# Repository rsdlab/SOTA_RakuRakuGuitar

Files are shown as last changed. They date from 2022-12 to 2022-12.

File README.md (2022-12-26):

 # 作品について　　

らくラクギターは誰でもかっこよく簡単に弾けるをコンセプトに開発されたギターである。　
　
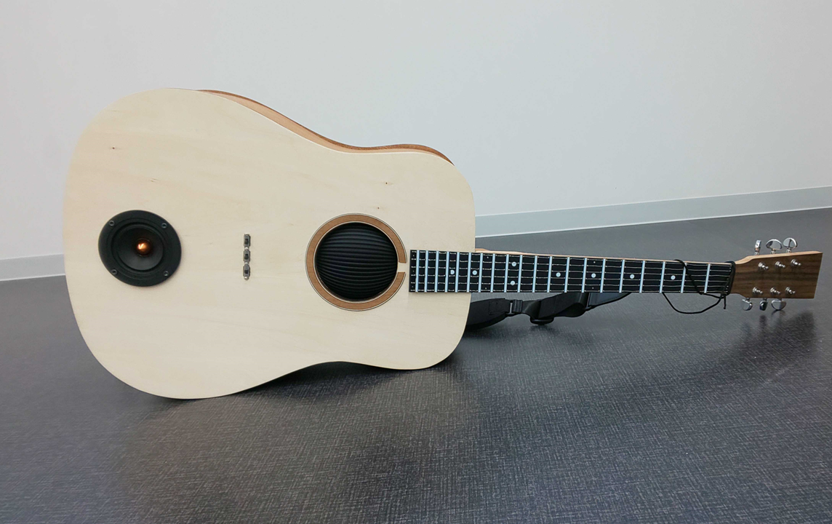
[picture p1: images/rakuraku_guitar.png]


マイコンはSONY製のSPRESENSEを使用している。　　

このらくラクギターには3種類のモードがある。　　

* ビギナーモード　ホイールを回すだけで演奏できるモード　　
* コードモード　弦を模したタッチセンサを1箇所もしくは2箇所押さえるだけで演奏できるモード　　
* マニュアルモード　本物のギターと同様に演奏できるモード　　

らくラクギターはM,m,7,sus4,dim,aug,M7,m7,7sus4に対応している。　　

らくラクギターの製作から実際に動かすまでの手順を以下に示す。　

1.　必要な部品の準備　　

2.　ギターのハード作成　　

3.　回路の作成　　

4.　動かすための準備　　

5.　らくラクギターの動かし方　

以下ではこれらを詳細に述べる。　　

 # 製作&動作手順　　
 ## 必要な部品の準備　　
下記の部品表の通りに各種部品を用意する。

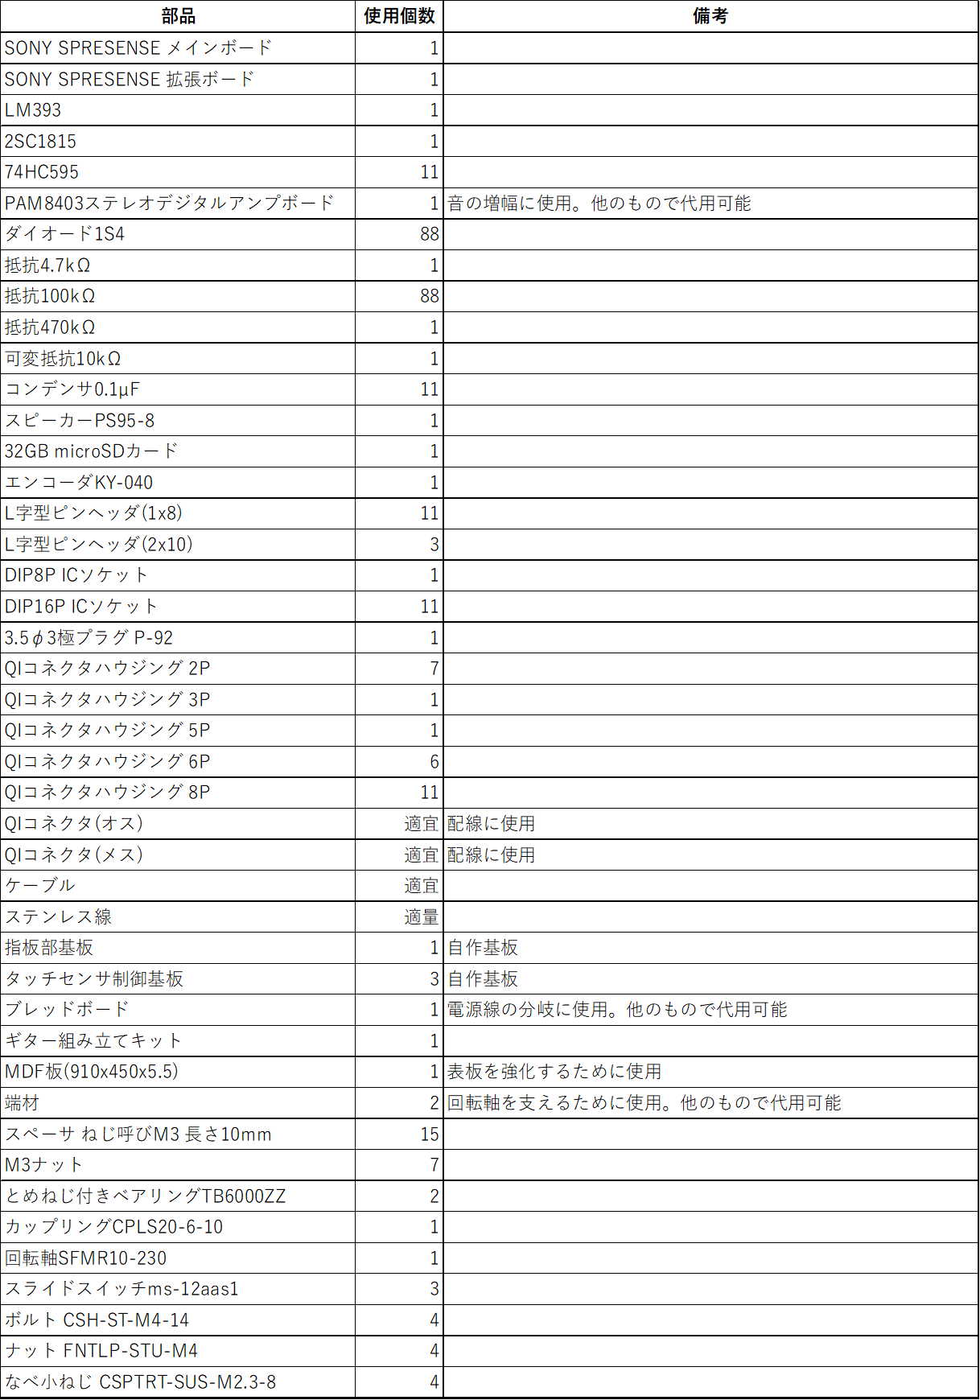
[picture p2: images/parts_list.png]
　　

## ギターのハード作成　　
こちらの動画を参考にギターを組み立てる。[youtubeへ移動](https://www.youtube.com/watch?v=TPaNkqSTSBw)　　
　　

表面の板を部品表にもあるベニヤ板で代替した。　　

タッチセンサやグランド線を通すためのスペースはギターのネックをノミや彫刻刀で彫る。　　

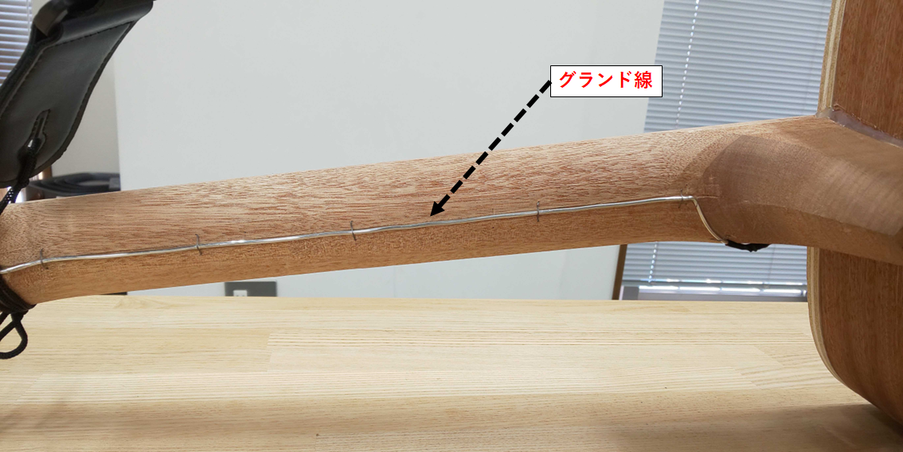
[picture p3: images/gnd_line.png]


また、設計図を基に固定を行う。　　

 ## 回路の作成　　
下記の回路図の通りに部品をはんだづけし、回路を作成する。

※下のタッチセンサ制御基板の配線の図も見てください。

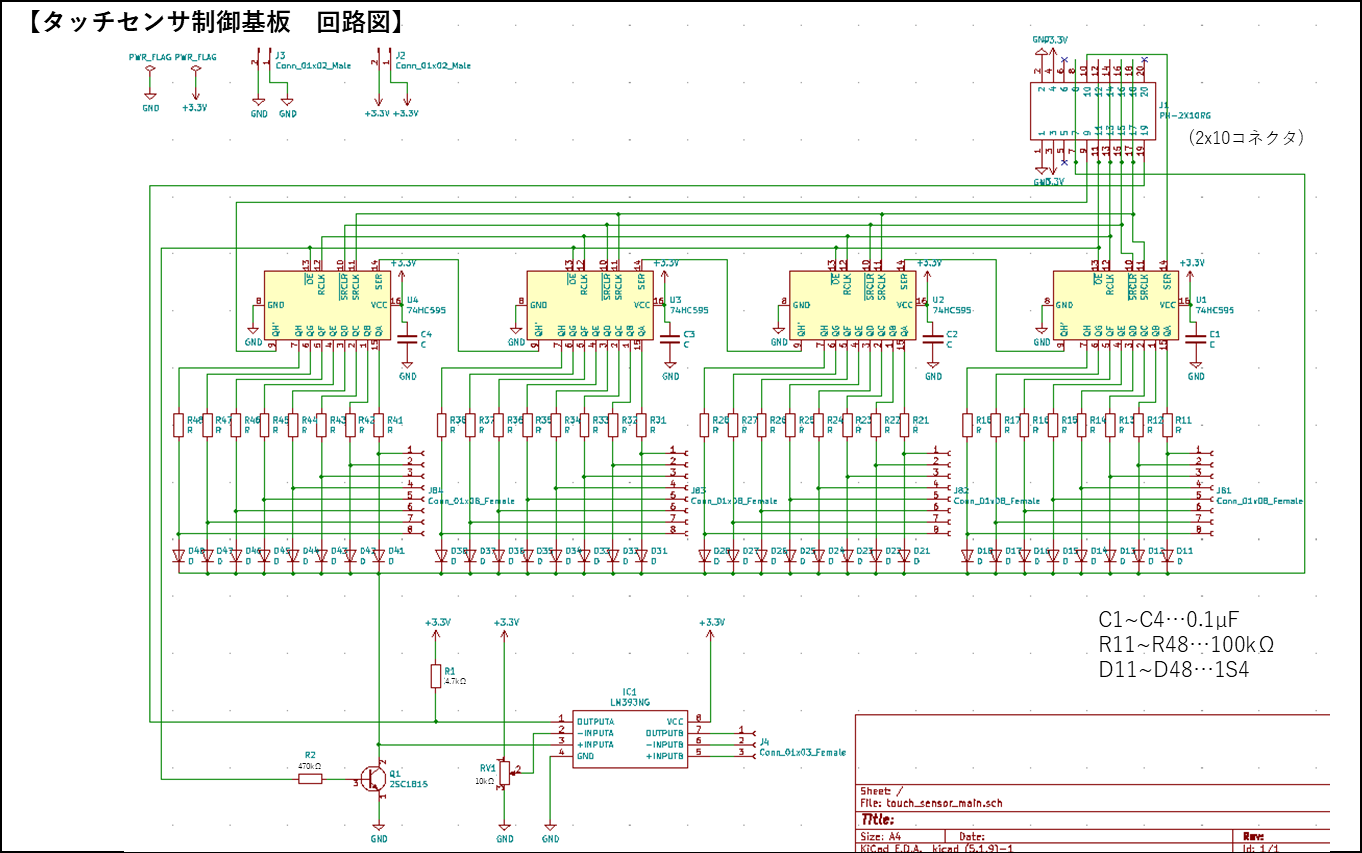
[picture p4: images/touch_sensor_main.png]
　

基板は[Elecrow](https://www.elecrow.com/)にてオーダメイドで発注したものである。

タッチセンサ制御部の基板データがPCB_data/touch_sensor_main、指版部の基板データがPCB_data/touch_sensor_touchとなっている。　　

 ## 動かすための準備　　
まずはSPRESENSEにプログラムを書き込む。  

SPRESENSEのセットアップを行う。詳しくは[こちら](https://developer.sony.com/develop/SPRESENSE/docs/arduino_set_up_ja.html)

書き込みはArduino IDEを用いる。ビルドも書き込みもメインコアからサブコア3まで1つづつしなければいけないので注意が必要である。メインコアへの書き込みはメモリを640KByteとすること。

次にSDカードに音源データを取り込む。SDカードにAとEのファイルを入れる。そしてSPRESENSEに差し込む。

回路やSPRESENSEの配線を完了させる。

SPRESENSEの配線とタッチセンサ制御基板の配線は以下の図の通りである。

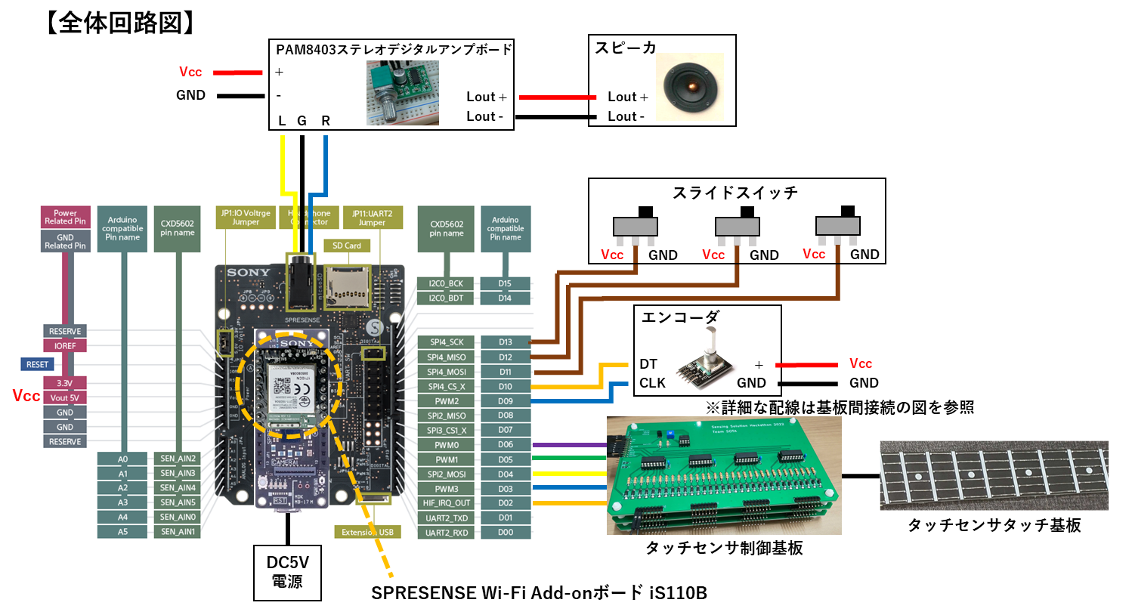
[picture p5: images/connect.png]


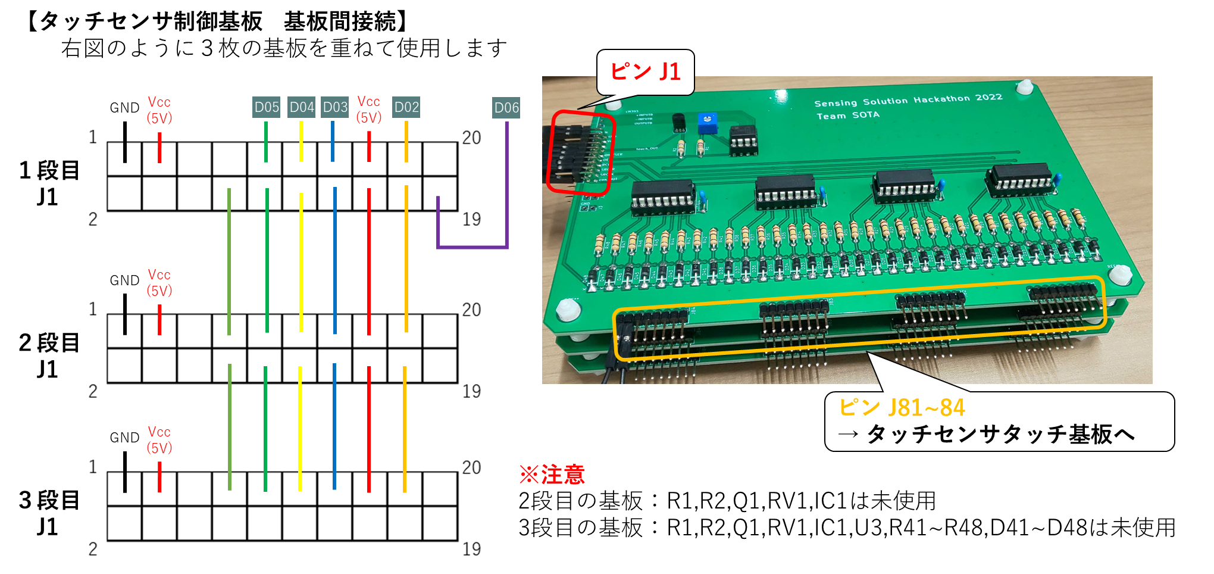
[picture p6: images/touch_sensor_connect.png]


そして設計図を基に裏板を固定する。　　

 ## らくラクギターの動かし方　　
まずは電源供給が必要である。　　

ギターからUSB(TypeA)が出ているのでモバイルバッテリーに接続する。

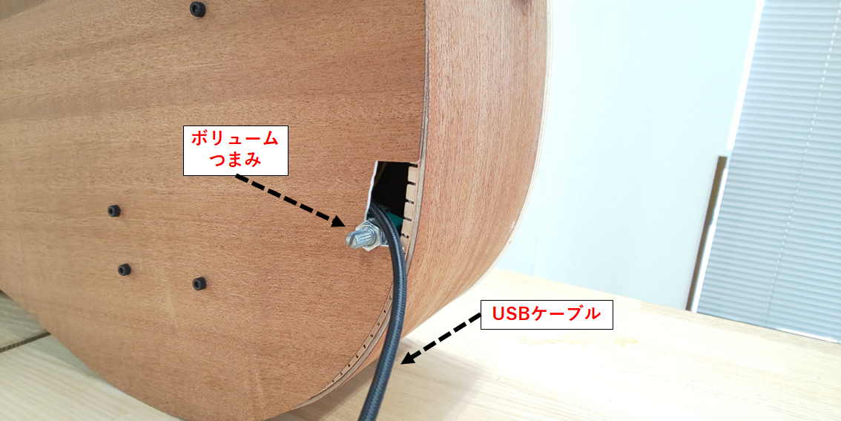
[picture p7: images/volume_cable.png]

　
そしてらくラクギターにはスイッチが3つついており、モードを選択できる。

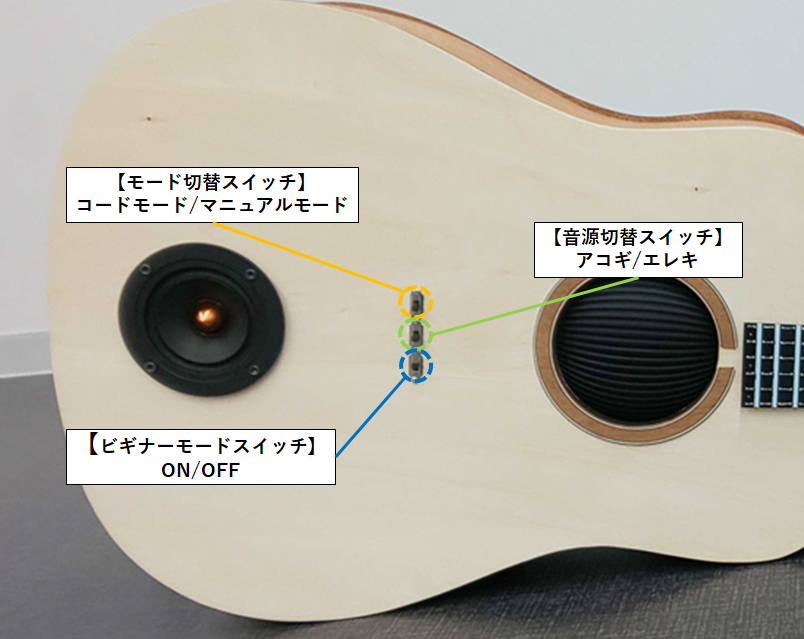
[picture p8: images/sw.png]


上から1つ目のスイッチを下、3つ目のスイッチを下にするとビギナーモードとなる。　　

上から1つ目のスイッチを下、3つ目のスイッチを上にするとコードモードとなる。

上から1つ目のスイッチを上にするとマニュアルモードとなる。　　

2つ目のスイッチを下にするとアコースティックギター、上にするとエレキギターの音が出せるようになる。　　

ギター裏についているボリュームを回すことで音量調整が可能である。(時計回りで音量が大きく、反時計回りで音量が小さくなる)　　

以下で各モードについて詳細に説明する。　　

共通事項として電源投入から一定時間経つとギターのジャーンと弾く音が勝手に再生される。これは準備完了の合図である。この合図があるまでホイールを回したり、タッチセンサを触ってはいけない。　　

ホイールの回転方向によってアップストロークとダウンストロークの切り替えが可能である。　　

 ### ビギナーモード　　
らくラクギターにPCから楽曲をとりこむ方法から説明する。　　

1. 楽曲を決定し、コード譜をテキストファイル(〇〇.txt)で作成する。　　
2. SPRESENSEに電源を投入する。
3. 楽曲を取り込む用のアプリケーション(rakuraku_guitar_gui.exe)を起動する。
4. 1にて作成したテキストファイルを選択する。　　
5. ジャーンという音がするまで待機し、音がなったらホイールを回すことでビギナーモードの演奏ができる。　　

注意点としては各コードは1ストローク分しか再生されない。なので、コードの変化するタイミングでホイールを回す必要がある。ただし、テキストファイルにコードを2回ずつ打つことで2ストロークづつにするなどテキストファイルの工夫である程度対応することは可能である。

ビギナーモードスイッチをOFFからONにするとコード譜の始めに戻る。　　

また、らくラクギターはコード(音)の変化にしか対応していないため,
タイミングについてはユーザーに完全に委ねられる。

 ### コードモード　　
1. SPRESENSEに電源を投入する。　　
2. ジャーンという音がするまで待機し、音がなったらコードモードの演奏ができる。タッチセンサを触りながらホイールを回すことで触っているセンサの位置に対応しているコードを鳴らすことができる。　　

コードの配置を以下に示す。

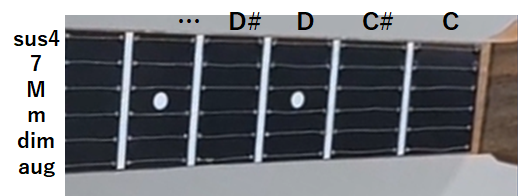
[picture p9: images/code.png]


1フレット目はCに、12フレット目はBに対応している。

M7はMと7の同時押し、m7はmと7の同時押し、7sus4はsus4と7に同時押しで演奏ができる。　　

どこも触れないままホイールを回すと6弦全てを開放したときの音が鳴る。　　

注意点としてはタッチセンサを触れるときに同時にネック裏に通してあるグランド線も触らないといけない。そうしないとタッチセンサの値が正しく得られずコードがうまく鳴らせない。　　

また、コードの判定は、触れていると判定されているタッチセンサと完全一致することでコードが決定する。逆に言えば他の余計な部分を触っていると正しくコードが認識されない。コードのリストに該当しない押さえ方でホイールを回した場合は無音となる。　　

 ### マニュアルモード　　
1. SPRESENSEに電源を投入する。　　
2. ジャーンという音がするまで待機し、音がなったらマニュアルモードの演奏ができる。タッチセンサを触りながらホイールを回すことで触っているセンサの位置に対応しているコードを鳴らすことができる。　　

マニュアルモードの押さえ方はローコード1種+ハイコード1種、ローコードが存在しない場合はハイコード2種を搭載している。　　

具体的な押さえ方は[ギタコン](https://guitar-concierge.com/chord/)の各コードの見出しになっているコード2種を実装している。ローコードがあるのにも関わらず見出しにローコードが無いコードについてはローコード1種+見出しのハイコード2種の計3種を実装している。　　

どこも触れないままホイールを回すと6弦全てを開放したときの音が鳴る。　　

注意点としてはコードモード同様、タッチセンサを触れるときに同時にネック裏に通してあるグランド線も触らないといけない。そうしないとタッチセンサの値が正しく得られずコードがうまく鳴らせない。　　

また、コードの判定は、触れていると判定されているタッチセンサと完全一致することでコードが決定する。逆に言えば他の余計な部分を触っていると正しくコードが認識されない。コードのリストに該当しない押さえ方でホイールを回した場合は無音となる。　　

開放弦とミュートについては触れないように設定してある。特にミュートの弦に触れないように注意が必要である。

# リポジトリの構成　　

* program：SPRESENSEに書き込むプログラム

* library：SPRESENSEに必要なライブラリの追加データ。詳細は中のreadmeを参照

* rakuraku_guitar_gui：PCで使う楽曲を取り込む用のアプリケーションとそのプログラム

* PCB_data：自作した基板のデータ

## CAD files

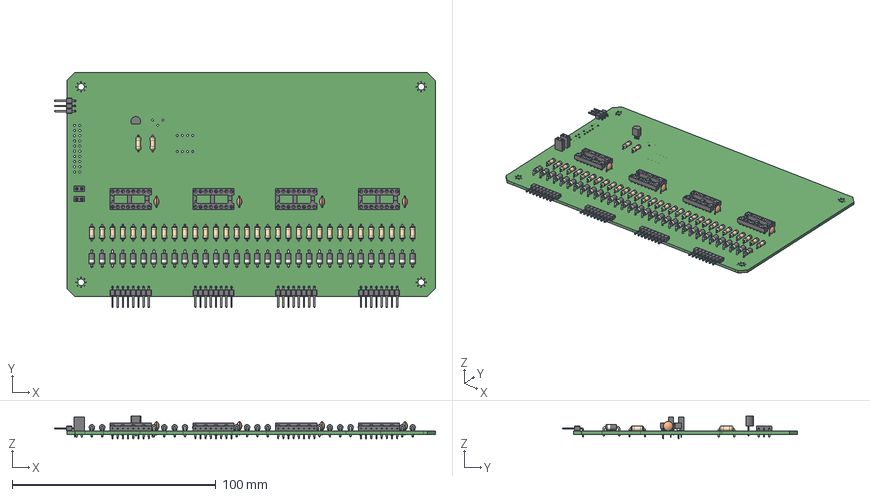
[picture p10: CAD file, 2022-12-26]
PCB_data/touch_sensor_main/touch_sensor_main.step
187.0 x 115.4 x 11.1 mm

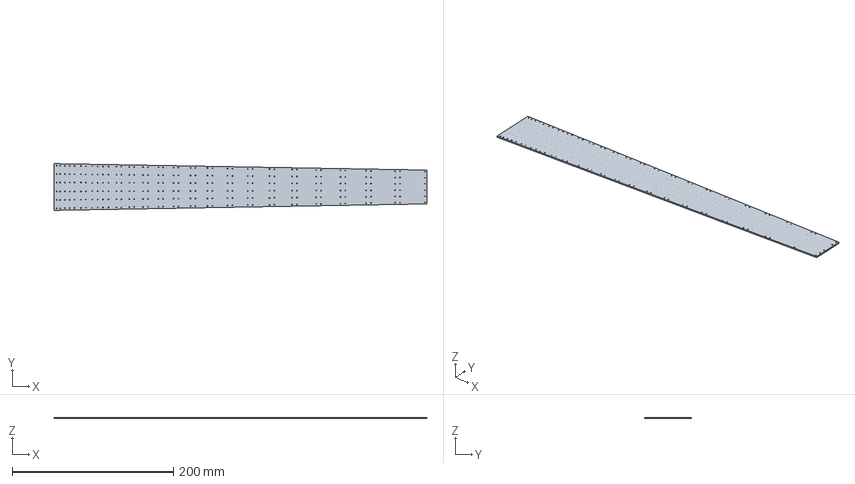
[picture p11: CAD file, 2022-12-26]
PCB_data/touch_sensor_touch/touch_sensor_touch.step
463.0 x 58.0 x 1.60 mm

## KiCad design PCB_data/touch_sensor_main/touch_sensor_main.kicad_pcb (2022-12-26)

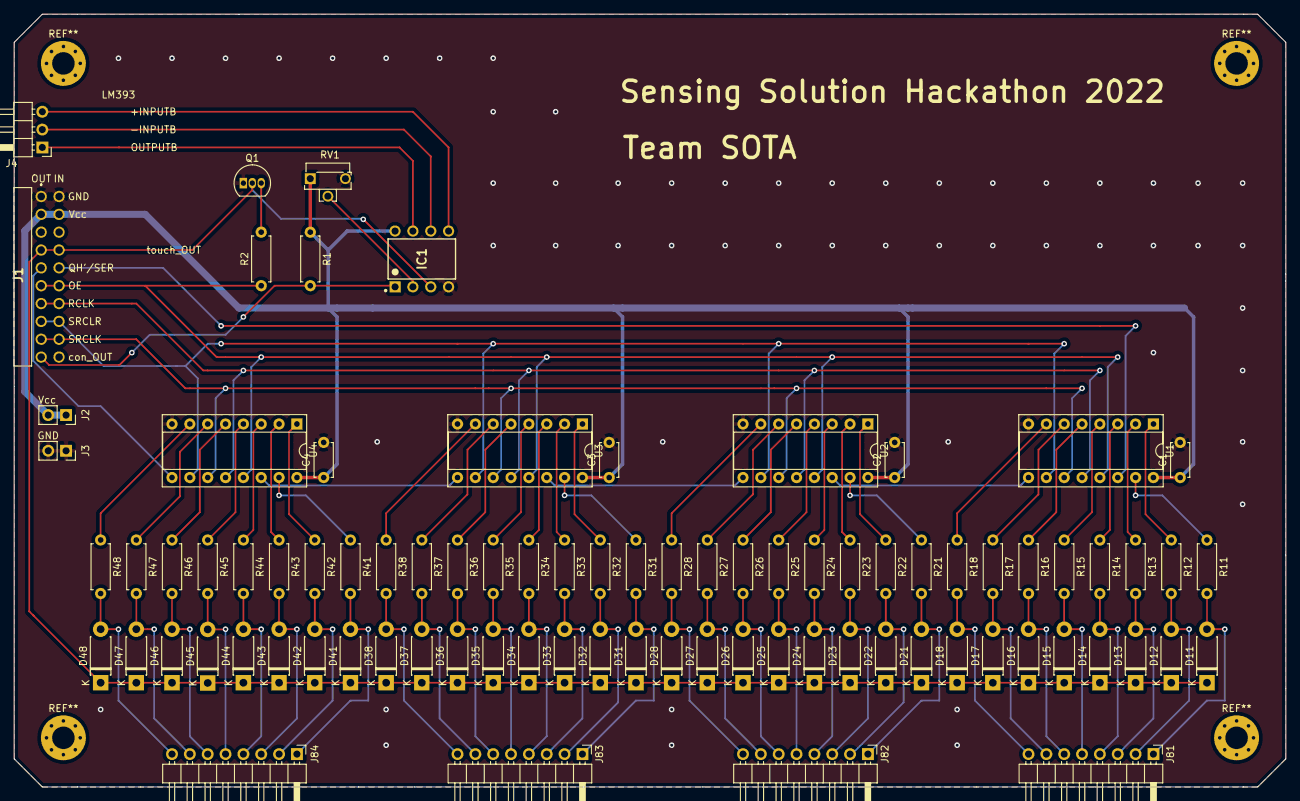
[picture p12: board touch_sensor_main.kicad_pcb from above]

Board: 2 copper layers, 181.0 x 110.0 mm, 85 parts (0 on the bottom side), 82 nets.

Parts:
C1, C2, C3, C4: C; C_Disc_D4.7mm_W2.5mm_P5.00mm
D11, D12, D13, D14, D15, D16, D17, D18, D21, D22, D23, D24, D25, D26, D27, D28, D31, D32, D33, D34, D35, D36, D37, D38, D41, D42, D43, D44, D45, D46, D47, D48: D; D_DO-41_SOD81_P7.62mm_Horizontal
IC1: LM393NG; DIP794W56P254L959H533Q8B
J1: PH-2X10RG; PH2X10RG
J2, J3: Conn_01x02_Male; PinSocket_1x02_P2.54mm_Vertical
J4: Conn_01x03_Female; PinHeader_1x03_P2.54mm_Horizontal
J81, J82, J83, J84: Conn_01x08_Female; PinHeader_1x08_P2.54mm_Horizontal
Q1: 2SC1815; TO-92_Inline
R1: 3k; R_Axial_DIN0207_L6.3mm_D2.5mm_P7.62mm_Horizontal
R2, R11, R12, R13, R14, R15, R16, R17, R18, R21, R22, R23, R24, R25, R26, R27, R28, R31, R32, R33, R34, R35, R36, R37, R38, R41, R42, R43, R44, R45, R46, R47, R48: R; R_Axial_DIN0207_L6.3mm_D2.5mm_P7.62mm_Horizontal
RV1: R_POT; Potentiometer_Runtron_RM-063_Horizontal
U1, U2, U3, U4: 74HC595; DIP-16_W7.62mm_Socket

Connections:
+3V3: C1.1, C2.1, C3.1, C4.1, IC1.8, J1.3, J1.4, J2.1, J2.2, R1.1, RV1.1, U1.16, U2.16, U3.16, U4.16
GND: C1.2, C2.2, C3.2, C4.2, IC1.4, J1.1, J1.2, J3.1, J3.2, Q1.1, RV1.3, U1.8, U2.8, U3.8, U4.8
unnamed: D11.1, D12.1, D13.1, D14.1, D15.1, D16.1, D17.1, D18.1, D21.1, D22.1, D23.1, D24.1, D25.1, D26.1, D27.1, D28.1, D31.1, D32.1, D33.1, D34.1, D35.1, D36.1, D37.1, D38.1, D41.1, D42.1, D43.1, D44.1, D45.1, D46.1, D47.1, D48.1, IC1.3, J1.7, J1.8, Q1.2
unnamed: D11.2, J81.1, R11.2
unnamed: D12.2, J81.2, R12.2
unnamed: D13.2, J81.3, R13.2
unnamed: D14.2, J81.4, R14.2
unnamed: D15.2, J81.5, R15.2
unnamed: D16.2, J81.6, R16.2
unnamed: D17.2, J81.7, R17.2
unnamed: D18.2, J81.8, R18.2
unnamed: D21.2, J82.1, R21.2
unnamed: D22.2, J82.2, R22.2
unnamed: D23.2, J82.3, R23.2
unnamed: D24.2, J82.4, R24.2
unnamed: D25.2, J82.5, R25.2
unnamed: D26.2, J82.6, R26.2
unnamed: D27.2, J82.7, R27.2
unnamed: D28.2, J82.8, R28.2
unnamed: D31.2, J83.1, R31.2
unnamed: D32.2, J83.2, R32.2
unnamed: D33.2, J83.3, R33.2
unnamed: D34.2, J83.4, R34.2
unnamed: D35.2, J83.5, R35.2
unnamed: D36.2, J83.6, R36.2
unnamed: D37.2, J83.7, R37.2
unnamed: D38.2, J83.8, R38.2
unnamed: D41.2, J84.1, R41.2
unnamed: D42.2, J84.2, R42.2
unnamed: D43.2, J84.3, R43.2
unnamed: D44.2, J84.4, R44.2
unnamed: D45.2, J84.5, R45.2
unnamed: D46.2, J84.6, R46.2
unnamed: D47.2, J84.7, R47.2
unnamed: D48.2, J84.8, R48.2
unnamed: IC1.1, J1.19, R1.2
unnamed: IC1.2, RV1.2
unnamed: IC1.5, J4.3
unnamed: IC1.6, J4.2
unnamed: IC1.7, J4.1
unnamed: J1.9, U4.9
unnamed: J1.10, U1.14
unnamed: J1.11, J1.12, R2.1, U1.13, U2.13, U3.13, U4.13
unnamed: J1.13, J1.14, U1.12, U2.12, U3.12, U4.12
unnamed: J1.15, J1.16, U1.10, U2.10, U3.10, U4.10
unnamed: J1.17, J1.18, U1.11, U2.11, U3.11, U4.11
unnamed: Q1.3, R2.2
unnamed: R11.1, U1.15
unnamed: R12.1, U1.1
unnamed: R13.1, U1.2
unnamed: R14.1, U1.3
unnamed: R15.1, U1.4
unnamed: R16.1, U1.5
unnamed: R17.1, U1.6
unnamed: R18.1, U1.7
unnamed: R21.1, U2.15
unnamed: R22.1, U2.1
unnamed: R23.1, U2.2
unnamed: R24.1, U2.3
unnamed: R25.1, U2.4
unnamed: R26.1, U2.5
unnamed: R27.1, U2.6
unnamed: R28.1, U2.7
unnamed: R31.1, U3.15
unnamed: R32.1, U3.1
unnamed: R33.1, U3.2
unnamed: R34.1, U3.3
unnamed: R35.1, U3.4
unnamed: R36.1, U3.5
unnamed: R37.1, U3.6
unnamed: R38.1, U3.7
unnamed: R41.1, U4.15
unnamed: R42.1, U4.1
unnamed: R43.1, U4.2
unnamed: R44.1, U4.3
unnamed: R45.1, U4.4
unnamed: R46.1, U4.5
unnamed: R47.1, U4.6
unnamed: R48.1, U4.7
unnamed: U1.9, U2.14
unnamed: U2.9, U3.14
unnamed: U3.9, U4.14

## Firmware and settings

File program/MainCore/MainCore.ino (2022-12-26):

//////////////////////////////  Main Core //////////////////////////////////////////////////////////////////////////////////////////
#ifdef SUBCORE  // SubCore指定時にはエラー
#error "Core selection is wrong!!"
#endif

#include <MP.h>
int subcore1 = 1;
int subcore2 = 2; 
int subcore3 = 3; 

#include <SDHCI.h>
#include <Audio.h>
#include <vector>
#include <stdint.h>

AudioClass *theAudio;
File myFile;
bool ErrEnd = false;
// error callback
static void audio_attention_cb(const ErrorAttentionParam *atprm)
{
    printf("************Attention!!!!!**********\n");
    //theAudio->stopPlayer(AudioClass::Player0);
    if (atprm->error_code == AS_ATTENTION_CODE_INFORMATION)
    {
        printf("*****************INFORMATION*******************\n");
        ErrEnd = true;
    }
    if (atprm->error_code == AS_ATTENTION_CODE_WARNING)
    {
        printf("****************WARNING*******************\n");
        ErrEnd = true;
    }
    if (atprm->error_code == AS_ATTENTION_CODE_ERROR)
    {
        printf("*****************ERROR*******************\n");
        ErrEnd = true;
    }
    if (atprm->error_code == AS_ATTENTION_CODE_FATAL)
    {
        printf("*****************FATAL*******************\n");
        ErrEnd = true;
    }
}

class PlayGuitar
{
    public:
        // wavファイル読込用
        struct Item 
        {
            int16_t note;
            String path;
        };
        
        PlayGuitar(const Item *table, size_t table_length);
        void setup();
        void begin();
        void end();
        bool sendNoteOn(int16_t note,int16_t volume);
        void sendNoteOff();
        //void sendNoteEnd();
        void update();
    private:
        // class
        SDClass sd;
        WavContainerFormatParser theParser;
        // wavの1つのデータ
        struct PcmData 
        {
            int16_t note;//番号
            String path;
            uint32_t offset;
            uint32_t size;
        };
        std::vector<PcmData> pcm_table_;
        // param
        int samplingrate = 192000;
        AsClkMode AS_CLKMODE = AS_CLKMODE_HIRES;//AS_CLKMODE_NORMAL or AS_CLKMODE_HIRES
        int bit = 16;//16 or 24
        int channel = 1;
        int max_buffer = 24000;
        uint8_t s_buffer[720];
        uint8_t sc_store_frames = 10;// 最初に読み込むframe数
        uint8_t sc_store_frames_loop = 1;//loopで読み込むframe数

        // sendNoteOn Off End updateで使う
        size_t supply_size = 0;
        uint32_t s_remain_size = 0;
        bool started = false;
        bool carry_over = false;
        bool file_open(int16_t note);
};
// wavのnote,pathをpcm_table_に書き込む
PlayGuitar::PlayGuitar(const Item *table, size_t table_length)
{
    printf("PlayGuitar Constructor\n");
    for (size_t i = 0; i < table_length; i++) 
    {
        PcmData pcm_data;
        pcm_data.note = table[i].note;
        pcm_data.path = table[i].path;
        pcm_table_.push_back(pcm_data);
    }
}
// wavのoffsetとsizeをpcm_table_に書き込む
void PlayGuitar::setup()
{
    printf("PlayGuitar setup\n");
    while (!sd.begin())
    {
        printf("please Insert SD card");
    }
    for (size_t i = 0; i < pcm_table_.size(); i++) 
    {
        fmt_chunk_t fmt;
        // sd cardからWavContainerFormatParserでwav情報読み込////////////////////////////////////////////////////////////////////////////////////////////////////////////////////////////////////み
        handel_wav_parser_t *handle = (handel_wav_parser_t *)theParser.parseChunk(("/mnt/sd0/"+pcm_table_[i].path).c_str(), &fmt);
        if (handle == NULL)
        {
           printf("Wav parser error note %d\n",pcm_table_[i].note);
           exit(1);
        }

        printf("framerate %d = %d\n",i,fmt.rate);
        printf("bit %d = %d\n",i,fmt.bit);
        pcm_table_[i].offset = handle->data_offset;
        pcm_table_[i].size = handle->data_size;
        theParser.resetParser((handel_wav_parser *)handle);
    }
    printf("note,       path, offset, size\n");
    for (size_t i = 0; i < pcm_table_.size(); i++) 
    {
        printf("%3d, %s, %d, %d\n",pcm_table_[i].note, pcm_table_[i].path.c_str(), pcm_table_[i].offset,pcm_table_[i].size);
    }
}
//Audioの初期設定
void PlayGuitar::begin()
{
    theAudio = AudioClass::getInstance();
    theAudio->begin(audio_attention_cb);// HWとの接続
    theAudio->setRenderingClockMode(AS_CLKMODE);
    theAudio->setPlayerMode(AS_SETPLAYER_OUTPUTDEVICE_SPHP, max_buffer,max_buffer);// 出力先,player1 maxbuffer,player2 maxbuffer
                                                                                       //sampling,16or24,mono or stereo
    err_t err = theAudio->initPlayer(AudioClass::Player0, AS_CODECTYPE_WAV, "/mnt/sd0/BIN",samplingrate,bit,channel);

    if (err != AUDIOLIB_ECODE_OK)
    {
      printf("Player0 initialize error\n");
      exit(1);
    }
    printf("initialization Audio Library\n");
}
// noteからwavファイルを検索し、
// wavファイルのoffsetの位置から読み込み、s_remain_sizeをset
bool PlayGuitar::file_open(int16_t note)
{
    // noteからwavファイルを検索
    int table_index_ = -1;
    for (size_t i = 0; i < pcm_table_.size(); i++) 
    {
        if (note == pcm_table_[i].note) 
        {
            table_index_ = i;
            break;
        }
    }
    myFile.close();
    if (table_index_ < 0) 
    {
        printf("error: note is nothing(note=%d)\n", note);
        return false;
    }
    //printf("play %s"pcm_table_[table_index_].path.c_str());
    myFile = sd.open(pcm_table_[table_index_].path.c_str());
    if (!myFile) 
    {
        printf("error: file open error(%s)\n", pcm_table_[table_index_].path.c_str());
        return false;
    }
    //offsetの位置から読込
    //wavファイルのsizeをset
    myFile.seek(pcm_table_[table_index_].offset);
    s_remain_size = pcm_table_[table_index_].size;
    return true;
}
// note番号と一致するものを最初のフレーム分、読み取る
// volumeも決まる
// started をset
bool PlayGuitar::sendNoteOn(int16_t note,int16_t volume)
{
    // reset
    supply_size = 0;
    carry_over = false;
    
    // 開始時のみファイルの読み込み
    if(!file_open(note))
    {
        printf("file can't read");
        return false;
    }
    // 入力が変化したらここのloopから抜け出せると良い
    for (uint8_t i = 0; i < sc_store_frames; i++)
    {
        supply_size = myFile.read(s_buffer, (s_remain_size < sizeof(s_buffer)) ? s_remain_size : sizeof(s_buffer));
        s_remain_size -= supply_size;
        

        //Serial.print("remain_size=");  
        //Serial.println(s_remain_size);

        int err = theAudio->writeFrames(AudioClass::Player0, s_buffer, supply_size);
        //Serial.print("first write");  
        //  開始時のみチェック
        if (err != AUDIOLIB_ECODE_OK)
        {
            Serial.println("SUDIOLIB_ECODE_OK");
            break;
        }
        //  終了
        if (s_remain_size == 0)
        {
            break;
        }
    }
    theAudio->setVolume(volume);  
    theAudio->startPlayer(AudioClass::Player0);
    started = true;
    //puts("Play!");
    return true;
}
// startedの時、数フレーム分読み取る
// s_remain_sizeが0になったら終了し、sendNoteOff(startedをreset)
void PlayGuitar::update()
{
    if(started)
    {
        for (uint8_t i = 0; i < sc_store_frames_loop; i++)
        {
            if(!carry_over)
            {
                supply_size = myFile.read(s_buffer, (s_remain_size < sizeof(s_buffer)) ? s_remain_size : sizeof(s_buffer));
                s_remain_size -= supply_size;
            }
            carry_over = false;
            //sbufferのsupply_size（読み取れた量）をFIFOに変換
            int err = theAudio->writeFrames(AudioClass::Player0, s_buffer, supply_size);

            // bufferが満タン
            if (err == AUDIOLIB_ECODE_SIMPLEFIFO_ERROR)
            {
                //Serial.println("SUDIOLIB_ECODE_SIMPLEFIFO_ERROR");
                carry_over = true;
                break;
            }
            else
            {
                //Serial.println("not full");
            }
            //Serial.println("s_remain_size =");
            //Serial.println(s_remain_size);
            // 終了
            if (s_remain_size == 0)
            {
                //Serial.print("remain_size =0");
                sendNoteOff();
                break;
            }
        }
    }
}
// 再生をstopし、startedをreset
void PlayGuitar::sendNoteOff()
{
    if(started)
    {
        theAudio->stopPlayer(AudioClass::Player0,AS_STOPPLAYER_NORMAL);
        started = false;
    }
}
//void PlayGuitar::sendNoteEnd()
//{
//    if(started)
//    {
//        theAudio->stopPlayer(AudioClass::Player0);
//        started = false;
//    }
//}
// 終了
void PlayGuitar::end()
{
    theAudio->setReadyMode();
    theAudio->end();
    printf("Exit player\n");
    exit(1);
}

//////////////////////////////////////////////////////////////////////////////////////////////////
///////////////////////////////////////////////////////////////////////////////////////////////////////////////////////
const PlayGuitar::Item table[437] = {
    {999,"A/free_u.wav"}, // setup.wav
    {-1,"A/free_u.wav"}, // A/free_u.wav
    {-11,"A/Caug_u.wav"},
    {-12,"A/Cdim_u.wav"},
    {-13,"A/CM_u.wav"},
    {-14,"A/Cm__u.wav"},
    {-15,"A/C7_u.wav"},
    {-16,"A/Csus4_u.wav"},
    {-17,"A/CM7_u.wav"},
    {-18,"A/Cm7__u.wav"},
    {-19,"A/C7sus4_u.wav"},
    {-21,"A/C#aug_u.wav"},
    {-22,"A/C#dim_u.wav"},
    {-23,"A/C#M_u.wav"},
    {-24,"A/C#m__u.wav"},
    {-25,"A/C#7_u.wav"},
    {-26,"A/C#sus4_u.wav"},
    {-27,"A/C#M7_u.wav"},
    {-28,"A/C#m7__u.wav"},
    {-29,"A/C#7sus4_u.wav"},
    {-31,"A/Daug_u.wav"},
    {-32,"A/Ddim_u.wav"},
    {-33,"A/DM_u.wav"},
    {-34,"A/Dm__u.wav"},
    {-35,"A/D7_u.wav"},
    {-36,"A/Dsus4_u.wav"},
    {-37,"A/DM7_u.wav"},
    {-38,"A/Dm7__u.wav"},
    {-39,"A/D7sus4_u.wav"},
    {-41,"A/D#aug_u.wav"},
    {-42,"A/D#dim_u.wav"},
    {-43,"A/D#M_u.wav"},
    {-44,"A/D#m__u.wav"},
    {-45,"A/D#7_u.wav"},
    {-46,"A/D#sus4_u.wav"},
    {-47,"A/D#M7_u.wav"},
    {-48,"A/D#m7__u.wav"},
    {-49,"A/D#7sus4_u.wav"},
    {-51,"A/Eaug_u.wav"},
    {-52,"A/Edim_u.wav"},
    {-53,"A/EM_u.wav"},
    {-54,"A/Em__u.wav"},
    {-55,"A/E7_u.wav"},
    {-56,"A/Esus4_u.wav"},
    {-57,"A/EM7_u.wav"},
    {-58,"A/Em7__u.wav"},
    {-59,"A/E7sus4_u.wav"},
    {-61,"A/Faug_u.wav"},
    {-62,"A/Fdim_u.wav"},
    {-63,"A/FM_u.wav"},
    {-64,"A/Fm__u.wav"},
    {-65,"A/F7_u.wav"},
    {-66,"A/Fsus4_u.wav"},
    {-67,"A/FM7_u.wav"},
    {-68,"A/Fm7__u.wav"},
    {-69,"A/F7sus4_u.wav"},
    {-71,"A/F#aug_u.wav"},
    {-72,"A/F#dim_u.wav"},
    {-73,"A/F#M_u.wav"},
    {-74,"A/F#m__u.wav"},
    {-75,"A/F#7_u.wav"},
    {-76,"A/F#sus4_u.wav"},
    {-77,"A/F#M7_u.wav"},
    {-78,"A/F#m7__u.wav"},
    {-79,"A/F#7sus4_u.wav"},
    {-81,"A/Gaug_u.wav"},
    {-82,"A/Gdim_u.wav"},
    {-83,"A/GM_u.wav"},
    {-84,"A/Gm__u.wav"},
    {-85,"A/G7_u.wav"},
    {-86,"A/Gsus4_u.wav"},
    {-87,"A/GM7_u.wav"},
    {-88,"A/Gm7__u.wav"},
    {-89,"A/G7sus4_u.wav"},
    {-91,"A/G#aug_u.wav"},
    {-92,"A/G#dim_u.wav"},
    {-93,"A/G#M_u.wav"},
    {-94,"A/G#m__u.wav"},
    {-95,"A/G#7_u.wav"},
    {-96,"A/G#sus4_u.wav"},
    {-97,"A/G#M7_u.wav"},
    {-98,"A/G#m7__u.wav"},
    {-99,"A/G#7sus4_u.wav"},
    {-101,"A/Aaug_u.wav"},
    {-102,"A/Adim_u.wav"},
    {-103,"A/AM_u.wav"},
    {-104,"A/Am__u.wav"},
    {-105,"A/A7_u.wav"},
    {-106,"A/Asus4_u.wav"},
    {-107,"A/AM7_u.wav"},
    {-108,"A/Am7__u.wav"},
    {-109,"A/A7sus4_u.wav"},
    {-111,"A/A#aug_u.wav"},
    {-112,"A/A#dim_u.wav"},
    {-113,"A/A#M_u.wav"},
    {-114,"A/A#m__u.wav"},
    {-115,"A/A#7_u.wav"},
    {-116,"A/A#sus4_u.wav"},
    {-117,"A/A#M7_u.wav"},
    {-118,"A/A#m7__u.wav"},
    {-119,"A/A#7sus4_u.wav"},
    {-121,"A/Baug_u.wav"},
    {-122,"A/Bdim_u.wav"},
    {-123,"A/BM_u.wav"},
    {-124,"A/Bm__u.wav"},
    {-125,"A/B7_u.wav"},
    {-126,"A/Bsus4_u.wav"},
    {-127,"A/BM7_u.wav"},
    {-128,"A/Bm7__u.wav"},
    {-129,"A/B7sus4_u.wav"},
    {1,"A/free_d.wav"}, // A/free_d.wav
    {11,"A/Caug_d.wav"},
    {12,"A/Cdim_d.wav"},
    {13,"A/CM_d.wav"},
    {14,"A/Cm__d.wav"},
    {15,"A/C7_d.wav"},
    {16,"A/Csus4_d.wav"},
    {17,"A/CM7_d.wav"},
    {18,"A/Cm7__d.wav"},
    {19,"A/C7sus4_d.wav"},
    {21,"A/C#aug_d.wav"},
    {22,"A/C#dim_d.wav"},
    {23,"A/C#M_d.wav"},
    {24,"A/C#m__d.wav"},
    {25,"A/C#7_d.wav"},
    {26,"A/C#sus4_d.wav"},
    {27,"A/C#M7_d.wav"},
    {28,"A/C#m7__d.wav"},
    {29,"A/C#7sus4_d.wav"},
    {31,"A/Daug_d.wav"},
    {32,"A/Ddim_d.wav"},
    {33,"A/DM_d.wav"},
    {34,"A/Dm__d.wav"},
    {35,"A/D7_d.wav"},
    {36,"A/Dsus4_d.wav"},
    {37,"A/DM7_d.wav"},
    {38,"A/Dm7__d.wav"},
    {39,"A/D7sus4_d.wav"},
    {41,"A/D#aug_d.wav"},
    {42,"A/D#dim_d.wav"},
    {43,"A/D#M_d.wav"},
    {44,"A/D#m__d.wav"},
    {45,"A/D#7_d.wav"},
    {46,"A/D#sus4_d.wav"},
    {47,"A/D#M7_d.wav"},
    {48,"A/D#m7__d.wav"},
    {49,"A/D#7sus4_d.wav"},
    {51,"A/Eaug_d.wav"},
    {52,"A/Edim_d.wav"},
    {53,"A/EM_d.wav"},
    {54,"A/Em__d.wav"},
    {55,"A/E7_d.wav"},
    {56,"A/Esus4_d.wav"},
    {57,"A/EM7_d.wav"},
    {58,"A/Em7__d.wav"},
    {59,"A/E7sus4_d.wav"},
    {61,"A/Faug_d.wav"},
    {62,"A/Fdim_d.wav"},
    {63,"A/FM_d.wav"},
    {64,"A/Fm__d.wav"},
    {65,"A/F7_d.wav"},
    {66,"A/Fsus4_d.wav"},
    {67,"A/FM7_d.wav"},
    {68,"A/Fm7__d.wav"},
    {69,"A/F7sus4_d.wav"},
    {71,"A/F#aug_d.wav"},
    {72,"A/F#dim_d.wav"},
    {73,"A/F#M_d.wav"},
    {74,"A/F#m__d.wav"},
    {75,"A/F#7_d.wav"},
    {76,"A/F#sus4_d.wav"},
    {77,"A/F#M7_d.wav"},
    {78,"A/F#m7__d.wav"},
    {79,"A/F#7sus4_d.wav"},
    {81,"A/Gaug_d.wav"},
    {82,"A/Gdim_d.wav"},
    {83,"A/GM_d.wav"},
    {84,"A/Gm__d.wav"},
    {85,"A/G7_d.wav"},
    {86,"A/Gsus4_d.wav"},
    {87,"A/GM7_d.wav"},
    {88,"A/Gm7__d.wav"},
    {89,"A/G7sus4_d.wav"},
    {91,"A/G#aug_d.wav"},
    {92,"A/G#dim_d.wav"},
    {93,"A/G#M_d.wav"},
    {94,"A/G#m__d.wav"},
    {95,"A/G#7_d.wav"},
    {96,"A/G#sus4_d.wav"},
    {97,"A/G#M7_d.wav"},
    {98,"A/G#m7__d.wav"},
    {99,"A/G#7sus4_d.wav"},
    {101,"A/Aaug_d.wav"},
    {102,"A/Adim_d.wav"},
    {103,"A/AM_d.wav"},
    {104,"A/Am__d.wav"},
    {105,"A/A7_d.wav"},
    {106,"A/Asus4_d.wav"},
    {107,"A/AM7_d.wav"},
    {108,"A/Am7__d.wav"},
    {109,"A/A7sus4_d.wav"},
    {111,"A/A#aug_d.wav"},
    {112,"A/A#dim_d.wav"},
    {113,"A/A#M_d.wav"},
    {114,"A/A#m__d.wav"},
    {115,"A/A#7_d.wav"},
    {116,"A/A#sus4_d.wav"},
    {117,"A/A#M7_d.wav"},
    {118,"A/A#m7__d.wav"},
    {119,"A/A#7sus4_d.wav"},
    {121,"A/Baug_d.wav"},
    {122,"A/Bdim_d.wav"},
    {123,"A/BM_d.wav"},
    {124,"A/Bm__d.wav"},
    {125,"A/B7_d.wav"},
    {126,"A/Bsus4_d.wav"},
    {127,"A/BM7_d.wav"},
    {128,"A/Bm7__d.wav"},
    {129,"A/B7sus4_d.wav"},
    {-1001,"E/free_u.wav"},// E/free_u.wav
    {-1011,"E/Caug_u.wav"},
    {-1012,"E/Cdim_u.wav"},
    {-1013,"E/CM_u.wav"},
    {-1014,"E/Cm__u.wav"},
    {-1015,"E/C7_u.wav"},
    {-1016,"E/Csus4_u.wav"},
    {-1017,"E/CM7_u.wav"},
    {-1018,"E/Cm7__u.wav"},
    {-1019,"E/C7sus4_u.wav"},
    {-1021,"E/C#aug_u.wav"},
    {-1022,"E/C#dim_u.wav"},
    {-1023,"E/C#M_u.wav"},
    {-1024,"E/C#m__u.wav"},
    {-1025,"E/C#7_u.wav"},
    {-1026,"E/C#sus4_u.wav"},
    {-1027,"E/C#M7_u.wav"},
    {-1028,"E/C#m7__u.wav"},
    {-1029,"E/C#7sus4_u.wav"},
    {-1031,"E/Daug_u.wav"},
    {-1032,"E/Ddim_u.wav"},
    {-1033,"E/DM_u.wav"},
    {-1034,"E/Dm__u.wav"},
    {-1035,"E/D7_u.wav"},
    {-1036,"E/Dsus4_u.wav"},
    {-1037,"E/DM7_u.wav"},
    {-1038,"E/Dm7__u.wav"},
    {-1039,"E/D7sus4_u.wav"},
    {-1041,"E/D#aug_u.wav"},
    {-1042,"E/D#dim_u.wav"},
    {-1043,"E/D#M_u.wav"},
    {-1044,"E/D#m__u.wav"},
    {-1045,"E/D#7_u.wav"},
    {-1046,"E/D#sus4_u.wav"},
    {-1047,"E/D#M7_u.wav"},
    {-1048,"E/D#m7__u.wav"},
    {-1049,"E/D#7sus4_u.wav"},
    {-1051,"E/Eaug_u.wav"},
    {-1052,"E/Edim_u.wav"},
    {-1053,"E/EM_u.wav"},
    {-1054,"E/Em__u.wav"},
    {-1055,"E/E7_u.wav"},
    {-1056,"E/Esus4_u.wav"},
    {-1057,"E/EM7_u.wav"},
    {-1058,"E/Em7__u.wav"},
    {-1059,"E/E7sus4_u.wav"},
    {-1061,"E/Faug_u.wav"},
    {-1062,"E/Fdim_u.wav"},
    {-1063,"E/FM_u.wav"},
    {-1064,"E/Fm__u.wav"},
    {-1065,"E/F7_u.wav"},
    {-1066,"E/Fsus4_u.wav"},
    {-1067,"E/FM7_u.wav"},
    {-1068,"E/Fm7__u.wav"},
    {-1069,"E/F7sus4_u.wav"},
    {-1071,"E/F#aug_u.wav"},
    {-1072,"E/F#dim_u.wav"},
    {-1073,"E/F#M_u.wav"},
    {-1074,"E/F#m__u.wav"},
    {-1075,"E/F#7_u.wav"},
    {-1076,"E/F#sus4_u.wav"},
    {-1077,"E/F#M7_u.wav"},
    {-1078,"E/F#m7__u.wav"},
    {-1079,"E/F#7sus4_u.wav"},
    {-1081,"E/Gaug_u.wav"},
    {-1082,"E/Gdim_u.wav"},
    {-1083,"E/GM_u.wav"},
    {-1084,"E/Gm__u.wav"},
    {-1085,"E/G7_u.wav"},
    {-1086,"E/Gsus4_u.wav"},
    {-1087,"E/GM7_u.wav"},
    {-1088,"E/Gm7__u.wav"},
    {-1089,"E/G7sus4_u.wav"},
    {-1091,"E/G#aug_u.wav"},
    {-1092,"E/G#dim_u.wav"},
    {-1093,"E/G#M_u.wav"},
    {-1094,"E/G#m__u.wav"},
    {-1095,"E/G#7_u.wav"},
    {-1096,"E/G#sus4_u.wav"},
    {-1097,"E/G#M7_u.wav"},
    {-1098,"E/G#m7__u.wav"},
    {-1099,"E/G#7sus4_u.wav"},
    {-1101,"E/Aaug_u.wav"},
    {-1102,"E/Adim_u.wav"},
    {-1103,"E/AM_u.wav"},
    {-1104,"E/Am__u.wav"},
    {-1105,"E/A7_u.wav"},
    {-1106,"E/Asus4_u.wav"},
    {-1107,"E/AM7_u.wav"},
    {-1108,"E/Am7__u.wav"},
    {-1109,"E/A7sus4_u.wav"},
    {-1111,"E/A#aug_u.wav"},
    {-1112,"E/A#dim_u.wav"},
    {-1113,"E/A#M_u.wav"},
    {-1114,"E/A#m__u.wav"},
    {-1115,"E/A#7_u.wav"},
    {-1116,"E/A#sus4_u.wav"},
    {-1117,"E/A#M7_u.wav"},
    {-1118,"E/A#m7__u.wav"},
    {-1119,"E/A#7sus4_u.wav"},
    {-1121,"E/Baug_u.wav"},
    {-1122,"E/Bdim_u.wav"},
    {-1123,"E/BM_u.wav"},
    {-1124,"E/Bm__u.wav"},
    {-1125,"E/B7_u.wav"},
    {-1126,"E/Bsus4_u.wav"},
    {-1127,"E/BM7_u.wav"},
    {-1128,"E/Bm7__u.wav"},
    {-1129,"E/B7sus4_u.wav"},
    {1001,"E/free_d.wav"},// E/free_d.wav
    {1011,"E/Caug_d.wav"},
    {1012,"E/Cdim_d.wav"},
    {1013,"E/CM_d.wav"},
    {1014,"E/Cm__d.wav"},
    {1015,"E/C7_d.wav"},
    {1016,"E/Csus4_d.wav"},
    {1017,"E/CM7_d.wav"},
    {1018,"E/Cm7__d.wav"},
    {1019,"E/C7sus4_d.wav"},
    {1021,"E/C#aug_d.wav"},
    {1022,"E/C#dim_d.wav"},
    {1023,"E/C#M_d.wav"},
    {1024,"E/C#m__d.wav"},
    {1025,"E/C#7_d.wav"},
    {1026,"E/C#sus4_d.wav"},
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
void loop()
{
    //////////////////////加速判定 (subcore 2)//////////////////////////
    long now_time = micros();
    double receive_time_million = now_time - sub2_time;
    double receive_time = receive_time_million/1000000;
    if(receive_time>0.08)
    {
        int      ret2;
        int8_t   rcvid;
        MP.RecvTimeout(MP_RECV_POLLING);   
        ret2 = MP.Recv(&rcvid, &rcvdata2, subcore2);  // SubCore2からmsg受信
        if (ret2 < 0) {
            //printf("encorder can");
        }
        else
        {
            sub2_time = micros();
            printf("Encorder data=%d \n", rcvdata2);
            //音量の変更
            if(rcvdata2 == 1||rcvdata2 == 2)
            {
                volume = 50;
            }
            else
            {
                volume = -100;
            }
            speed_up = true;
        }
    }
    ///////////////////////receive code list (subcore 3)//////////////////////////
    MP.RecvTimeout(MP_RECV_POLLING);
    int      ret3;
    int8_t   msgid;
    MyPacket *packet;

    /* Receive message from SubCore */
    ret3 = MP.Recv(&msgid, &packet, subcore3);
    if (ret3 > 0) {
        //printf("%s\n", packet->message);
        char* note_message = packet->message;
        code_list = number(note_message);
        printf("size = %d\n",code_list.size());
        for(int i=0;i< code_list.size();i++)
        {
            printf("%d,",code_list[i]);
        }
        printf("\n");
        /* status -> ready */
        packet->status = 0;
        inst.sendNoteOff();
        inst.sendNoteOn(1001,-100);
    }
    ///////////////////////////////////////////////////////////////
    bool beginner_mode = digitalRead(Swich_13);
    if(beginner_mode_started == true&&beginner_mode == false)
    {
        beginner_mode_started = false;
    }
    if(speed_up)
    {
    //////////// beginner mode ///////////////////////////////////////
        if(beginner_mode)
        {
            printf("beginner mode = %d\n",beginner_mode_started);
            if(code_list.size()>0)
            {
                if(!beginner_mode_started)
                {
                    list_count = 0;
                    note = code_list[list_count];
                    beginner_mode_started = true;
                }
                else
                {
                    list_count = list_count+1;
                    if(list_count == code_list.size())
                    {
                        list_count = 0;
                    }
                    note = code_list[list_count];
                }
            }
        }
    /////////////// code or manual mode (subcore 1)//////////////////////////
        else
        {
            int      ret1;
            uint32_t rcvdata = 1;
            int8_t   rcvid = 1;
            ret1 = MP.Send(rcvid,rcvdata,subcore1);
            if(ret1<0)
                printf("fail connect SubCore1\n");
            else
            {
                //Serial.println("to 1 send success");
                MP.RecvTimeout(MP_RECV_BLOCKING);   
                ret1 = MP.Recv(&rcvid, &rcvdata, subcore1);  // SubCore1からmsg受
                if(ret1<0)
                    printf("can't receive SubCore1\n");
                else
                {
                    note = rcvdata;
                    printf("from SubCore1 data %d\n",note);
                }
            }

        }
    ////////////////// 音を鳴らす //////////////////////
        if(note == 10000)
        {

        }
        else
        {
            // elekiの場合
            bool Acoustic = digitalRead(Swich_12);
            if(!Acoustic)
            {
                note = note + 1000;
            }
            //ダウンストロークの場合
            if(rcvdata2 == 2||rcvdata2 == 3)
            {
                note = -note;
            }
            printf("play_number= %d\n",note);
            inst.sendNoteOff();
            inst.sendNoteOn(note,volume);
        }
        speed_up = false;
    }
    inst.update();
    return;
}

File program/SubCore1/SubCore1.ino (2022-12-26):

#if (SUBCORE != 1)  // SubCoreの指定
#error "Core selection is wrong!!"
#endif

#include <MP.h>
#include <vector>

using namespace std;
class Touch_Sensor
{
  private:
  //pin番号
    const uint8_t SRCLK = 2;
    const uint8_t RCLK = 3;
    const uint8_t G = 4;
    const uint8_t SER = 5;
    const uint8_t input_pin = 6;


  public:
    struct Touch_data
    {
        uint8_t note;
        vector<uint8_t> touch_number;
    };
  //初期設定
    void setup();
  //タッチセンサ処理
    void get_sensor(bool setup);
  //押されたタッチセンサ番号
    vector<uint8_t> touch_number;
};

void Touch_Sensor::setup() 
{
    pinMode(SRCLK, OUTPUT);//SRCLK
    pinMode(RCLK,  OUTPUT);//RCLK
    pinMode(SER,   OUTPUT);//SER
    pinMode(G,   OUTPUT);//G
    pinMode(input_pin, INPUT);//input_pin

    for(uint8_t j = 0; j < 10; j++)
        get_sensor(true);
    Serial.println("touch sensor set up completed !");
}

void Touch_Sensor::get_sensor(bool setup)
{
    //タッチセンサの数
    static int8_t touch_num = 88;
    static uint8_t touch_flag[88];
  //閾値
    static uint8_t touch_threshold[88] = {0};
  //タッチセンサの初期化
    for(uint8_t i = 0; i < touch_num; i++)
        touch_flag[i] = 0;
    touch_number.clear();

    delayMicroseconds(150);
    // 入力状態をHIGHにする
    digitalWrite(SER, HIGH);

    for (uint8_t i=0; i<touch_num; i++) {

        // 閾値決定のための変数
        uint8_t sub_threshold = 1;

        // シフトレジスタをシフトさせてSERピンの状態を記憶させる
        digitalWrite(SRCLK, LOW);
        delayMicroseconds(2);
        digitalWrite(SRCLK, HIGH);
        
        // シフトレジスタの状態をストレージレジスタへ反映させる
        digitalWrite(RCLK,  LOW);
        delayMicroseconds(2);
        digitalWrite(RCLK,  HIGH);

        //出力を有効にする
        digitalWrite(G, LOW);
        
        while(digitalRead(input_pin) != HIGH)
        {
            if (setup)
            {
                sub_threshold++;
            }
            else
            {
                touch_flag[i]++;
            }
        }
        if (setup)
        {
            //最大値を閾値とする
            if(sub_threshold > touch_threshold[i]){
                touch_threshold[i] = sub_threshold;
            }            
        }
        else
        {
            if(touch_flag[i] > touch_threshold[i])
            {
                touch_number.push_back(i); 
            }
        }

        delayMicroseconds(50);

        //出力を無効にする
        digitalWrite(G, HIGH);
        
        // 放電するまで待つ
        delayMicroseconds(200);

        // 以降の入力状態をLOWにする
        digitalWrite(SER, LOW);
    }
    // 閾値確認用
    // for(int j=0;j<88;j++){
    //   printf("%d,"touch_threshold[j]);
    // }
    // printf("\n");
}
///////////////////////////////////////////////////////////////////////////////////////////////////////////////////////
const uint16_t code_mode_size = 109;
const Touch_Sensor::Touch_data code_mode[109] = {
    {1, {}},
    {11, {0}},
    {12, {1}},
    {13, {2}},
    {14, {3}},
    {15, {4}},
    {16, {5}},
    {17, {2,4}},
    {18, {3,4}},
    {19, {4,5}},
    {21, {6}},
    {22, {7}},
    {23, {8}},
    {24, {9}},
    {25, {10}},
    {26, {11}},
    {27, {8,10}},
    {28, {9,10}},
    {29, {10,11}},
    {31, {12}},
    {32, {13}},
    {33, {14}},
    {34, {15}},
    {35, {16}},
    {36, {17}},
    {37, {14,16}},
    {38, {15,16}},
    {39, {16,17}},
    {41, {18}},
    {42, {19}},
    {43, {20}},
    {44, {21}},
    {45, {22}},
    {46, {23}},
    {47, {20,22}},
    {48, {21,22}},
    {49, {22,23}},
    {51, {24}},
    {52, {25}},
    {53, {26}},
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
};
/////////////////////////////
const uint16_t manual_mode_size = 225;
const Touch_Sensor::Touch_data manual_mode[225] = {
    {1, {}},
    {11, {3,4,8,13}},
    {11, {42,51,52,56}},
    {12, {13,20,22,27}},
    {12, {40,42,45}},
    {13, {4,8,13}},
    {13, {13,14,15,16,17,26,27,28}},
    {14, {2,4,13}},
    {14, {13,14,15,16,17,22,26,27}},
    {14, {42,43,44,45,46,47,55,56}},
    {15, {4,8,13,15}},
    {15, {13,14,15,16,17,26,28}},
    {16, {4,5,13,14}},
    {16, {13,14,15,16,17,26,27}},
    {17, {8,13}},
    {17, {42,46,50,51}},
    {18, {13,14,15,16,17,22,26}},
    {18, {42,43,44,45,46,47,55}},
    {19, {13,14,15,16,17,26,34}},
    {19, {42,43,44,45,46,47,55,57}},
    {21, {9,10,14,19}},
    {21, {53,57,58,62}},
    {22, {19,26,28,33}},
    {22, {46,48,51}},
    {23, {19,20,21,22,23,32,33,34}},
    {23, {48,49,50,51,52,53,57,61,62}},
    {24, {19,20,21,22,23,28,32,33}},
    {24, {48,49,50,51,52,53,61,62}},
    {25, {19,20,21,22,23,32,34}},
    {25, {48,49,50,51,52,53,57,61}},
    {26, {19,20,21,22,23,32,33,40}},
    {26, {48,49,50,51,52,53,61,62,63}},
    {27, {19,20,21,22,23,27,32,34}},
    {27, {48,52,56,57}},
    {28, {3,8,19}},
    {28, {19,20,21,22,23,28,32}},
    {28, {48,49,50,51,52,53,61}},
    {29, {19,20,21,22,23,32,40}},
    {29, {48,49,50,51,52,53,61,63}},
    {31, {11,15,16}},
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
};

////////////////////////////////////////////////////////////////////////////////////////////////////////////////////////////////////
Touch_Sensor touch_sensor;
#define Swich_11 (11)
int8_t   ret1;
void setup() 
{
    // シリアル通信設定
    Serial.begin(2000000);
    while (!Serial);
    touch_sensor.setup();
    pinMode(Swich_11, INPUT);

    // マルチコア起動
    ret1 = MP.begin();
    MP.RecvTimeout(MP_RECV_POLLING);   
    //　起動エラー
    // if (ret1 < 0) 
    //     printf("SubCore start error = %d\n", ret1);
}

void loop()
{
    uint16_t note = 10000;
    //タッチセンサの値を取得
    touch_sensor.get_sensor(false);
//    printf("touch_number:");
//    for(uint8_t i=0;i<touch_sensor.touch_number.size();i++)
//    {
//        printf("%d,",touch_sensor.touch_number[i]);
//    }
//    printf("\n");
    
    //対応した音の番号の出力
    bool Code_mode = digitalRead(Swich_11);
    if(Code_mode)
    {
        for(uint8_t i=0;i<code_mode_size;i++)
        {
            if(touch_sensor.touch_number.size() == code_mode[i].touch_number.size() && 
            equal(touch_sensor.touch_number.cbegin(),touch_sensor.touch_number.cend(),code_mode[i].touch_number.cbegin()))
            {
                note = code_mode[i].note;
                break;
            }
            
        }
    }
    else
    {
        for(uint8_t i=0;i<manual_mode_size;i++)
        {
            if(touch_sensor.touch_number.size() == manual_mode[i].touch_number.size() && 
            equal(touch_sensor.touch_number.cbegin(),touch_sensor.touch_number.cend(),manual_mode[i].touch_number.cbegin()))
            {
                note = manual_mode[i].note;
                break;
            }
        }
    }
    int8_t msgid;
    uint32_t msgdata;
    /* Echo back */
    ret1 = MP.Recv(&msgid, &msgdata);  // MainCoreからmsg受信
    if (ret1 < 0) {
        //printf("SubCore1 fail connect Main = %d\n", ret1);
    }
    else
    {
        msgdata = note;
        ret1 = MP.Send(msgid, msgdata);  
         //msg送信エラー
         if (ret1 < 0) 
            printf("SubCore 1 send error = %d\n", ret1);
         else
            printf("SubCore1 send: id=%d data=%d\n", msgid, msgdata);
    }
    return;
}
